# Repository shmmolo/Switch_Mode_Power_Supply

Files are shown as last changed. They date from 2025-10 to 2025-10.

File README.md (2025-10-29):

# 25 W @ 9 V Flyback SMPS Charger with USB-PD

A compact isolated Flyback SMPS delivering 25 W power for USB-C PD fast charging, designed around TI’s UCC28750 controller.

## Features
- 220 VAC input → 9 V / 5 V output
- USB-PD communication via IP2721
- UCC28750 PWM controller + optocoupler feedback
- Schottky rectification and snubber protection
- 2-layer PCB with ground plane and isolation gap

## Components
- **U1:** UCC28750 Flyback Controller  
- **Q1:** NMOS primary switch  
- **U2:** PC817 Optocoupler  
- **U3:** TL431 Voltage Reference  
- **U4:** IP2721 USB-PD Controller  
- **D1–D5:** GBU4K + SS310 Schottky diodes  
- **T1:** Flyback Transformer (custom)  
- **C1–C12:** Filtering capacitors

## Output Specs
| Mode | Voltage | Current | Power |
|---|---|---|---|
| Default | 5 V | 2.8 A | 14 W |
| USB-PD | 9 V | 2.8 A | 25 W |

## Notes
PCB under layout stage – final design will feature 2-layer structure with dedicated GND plane, thermal reliefs, and isolation.

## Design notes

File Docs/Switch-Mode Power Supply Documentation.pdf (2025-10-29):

# 25 W @ 9 V SMPS Charger (USB-PD)

## Overview

This project is a Switch-Mode Power Supply (SMPS) in flyback configuration, delivering 25 W output power at 9 V DC.
It features USB Power Delivery (PD) communication for fast charging via a USB Type-C port and uses the UCC28750 flyback controller for high-efficiency operation with isolated feedback.
The design follows modern compact-charger topologies, combining power, feedback, and communication circuits on a single 2-layer PCB (GND plane on the bottom).

## Key Specifications

Parameter | Value
Input Voltage | 220 – 240 VAC
Output Voltage | 5 V / 9 V (USB-PD)
Output Current | up to 2.8 A
Output Power | 25 W max
Topology | Isolated Flyback
Switching Controller | TI UCC28750
Feedback Isolation | TL431 + PC817 Optocoupler
USB-PD Controller | IP2721
Efficiency (target) | ≈ 85 %
Transformer | Custom 2P:1S Flyback, optimized for 25 W

## Functional Description

### 1. AC Rectification & Filtering

- Input 220 VAC enters through a Phoenix terminal block.
- A GBU4K full-bridge rectifier converts AC to DC.
- Three 10 µF electrolytic capacitors connected in parallel smooth the rectified DC.
- High-value resistor divider (R1–R3) provides startup and reference bias for the control stage.

### 2. Snubber & Protection Network

- The RC-D snubber (R4, R5, C4, D4) suppresses voltage spikes caused by transformer leakage inductance.
- D4 is an ultrafast Schottky diode, protecting the primary switch and improving efficiency.

### 3. Control Stage – UCC28750

- UCC28750 operates in primary-side regulation (PSR) with valley-switching PWM for low switching loss.
- It drives the Q1 NMOS transistor, switching current through the transformer’s primary winding.
- Current-sense resistor (R7) monitors switch current, while gate resistor (R6) limits EMI and overshoot.
- The controller dynamically adjusts frequency and duty cycle based on optocoupler feedback.

### 4. Feedback Regulation

- The secondary voltage is sensed through a TL431 precision reference (U3) and PC817 optocoupler (U2).
- When output voltage rises, TL431 conducts more, driving the optocoupler LED to adjust the duty cycle, maintaining stable regulation.
- This ensures precise and isolated voltage feedback between primary and secondary sides.

### 5. Output Rectification & Filtering

- The flyback transformer’s secondary output is rectified by D5 Schottky diode (low forward drop).
- Three 820 µF capacitors (C10–C12) filter the output to achieve low ripple and stable DC.

### 6. USB-PD Communication

- The IP2721 controller (U4) handles USB Power Delivery negotiation through CC1/CC2 lines.
- It communicates desired voltage/current profiles to the connected device (5 V / 9 V).
- Q2 NMOS acts as a high-side switch for VBUS control during protocol handshakes.
- Final output is provided via a USB Type-C receptacle, with shielding and ESD protection.

## PCB Design Overview

- 2-Layer PCB with bottom GND plane and isolated high-voltage creepage clearances.
- Primary and secondary grounds separated with safety isolation gap.
- Short and wide switch-node trace for reduced ringing and EMI.
- Transformer footprint (T1) centered for balanced heat distribution.
- Compact layout suitable for integration in a USB-C wall charger enclosure.

## Applications

- USB-C fast chargers (5 V / 9 V profiles)
- Compact SMPS adapters up to 25 W
- Isolated DC power sources for embedded systems
- Educational design for USB-PD + Flyback topology integration

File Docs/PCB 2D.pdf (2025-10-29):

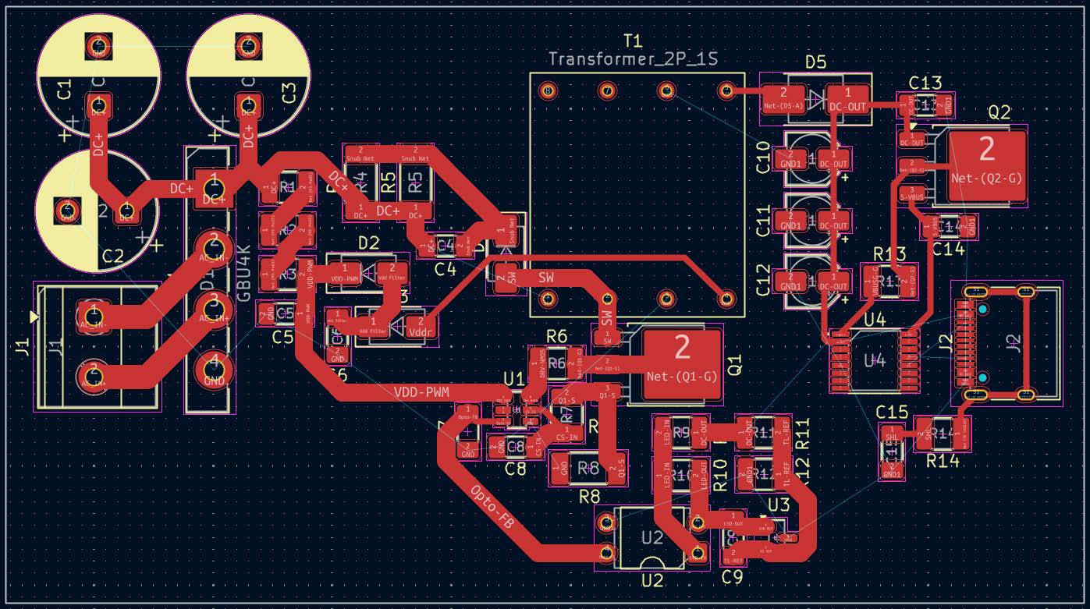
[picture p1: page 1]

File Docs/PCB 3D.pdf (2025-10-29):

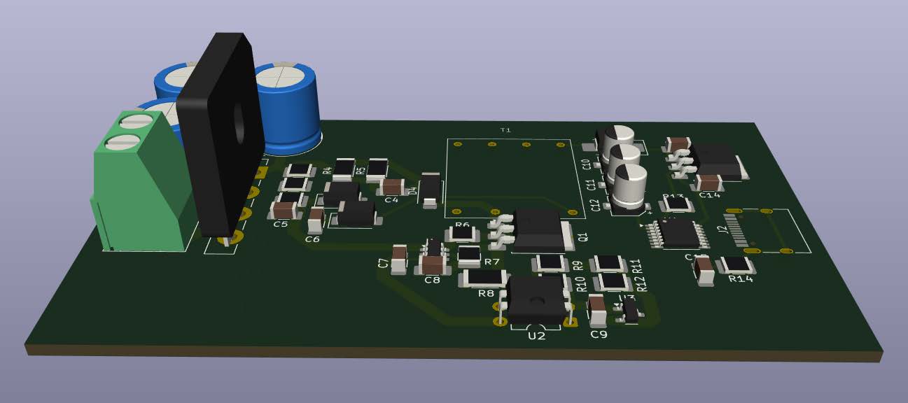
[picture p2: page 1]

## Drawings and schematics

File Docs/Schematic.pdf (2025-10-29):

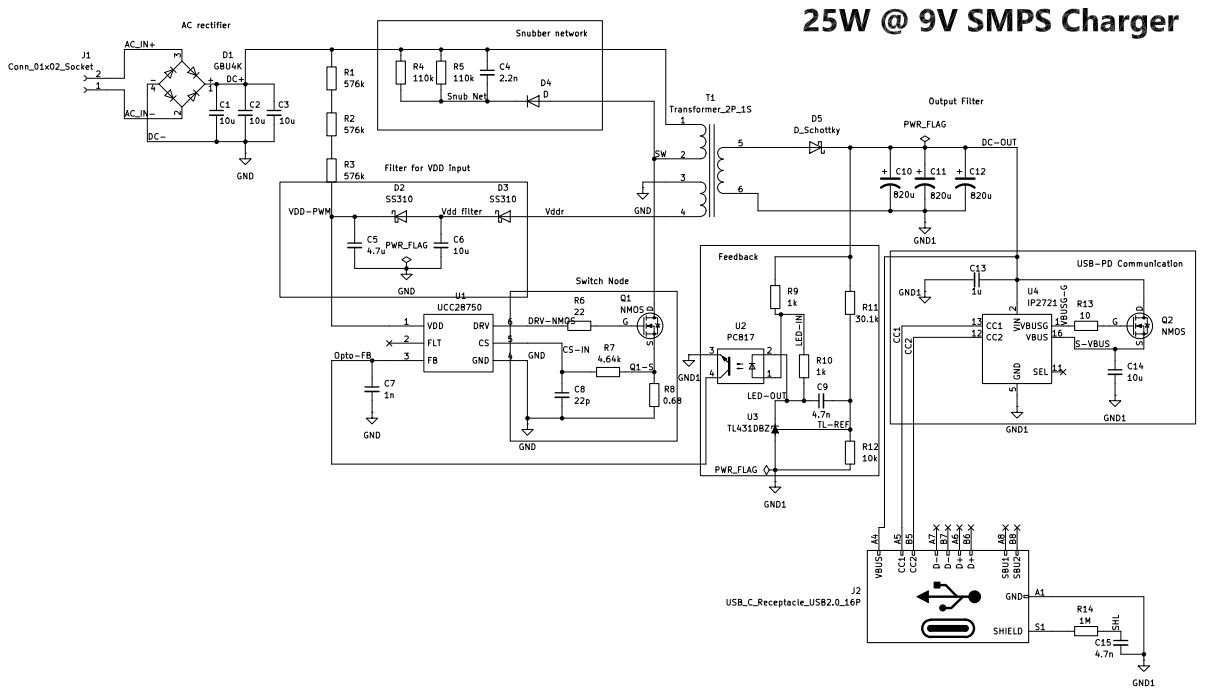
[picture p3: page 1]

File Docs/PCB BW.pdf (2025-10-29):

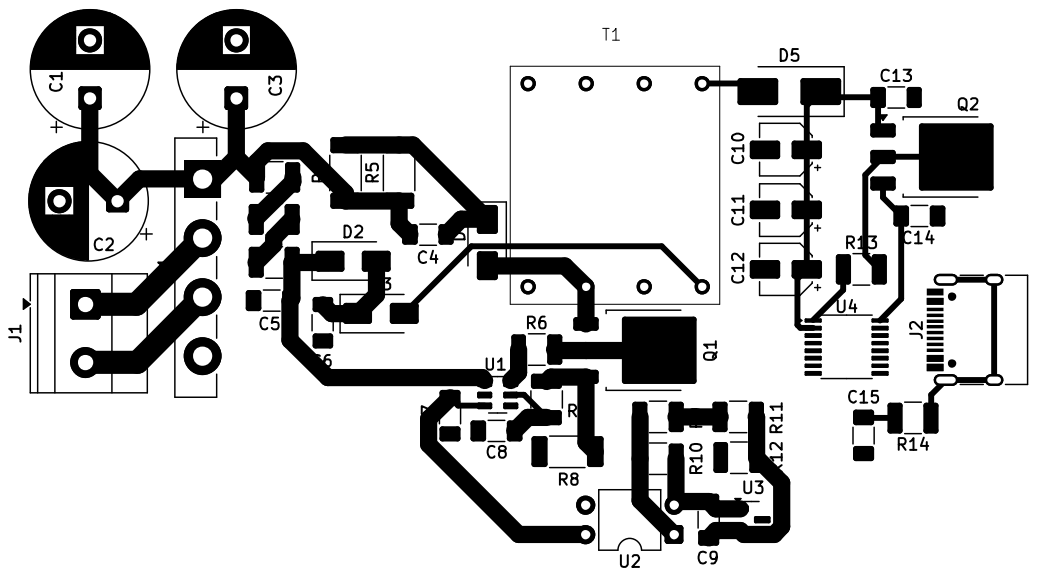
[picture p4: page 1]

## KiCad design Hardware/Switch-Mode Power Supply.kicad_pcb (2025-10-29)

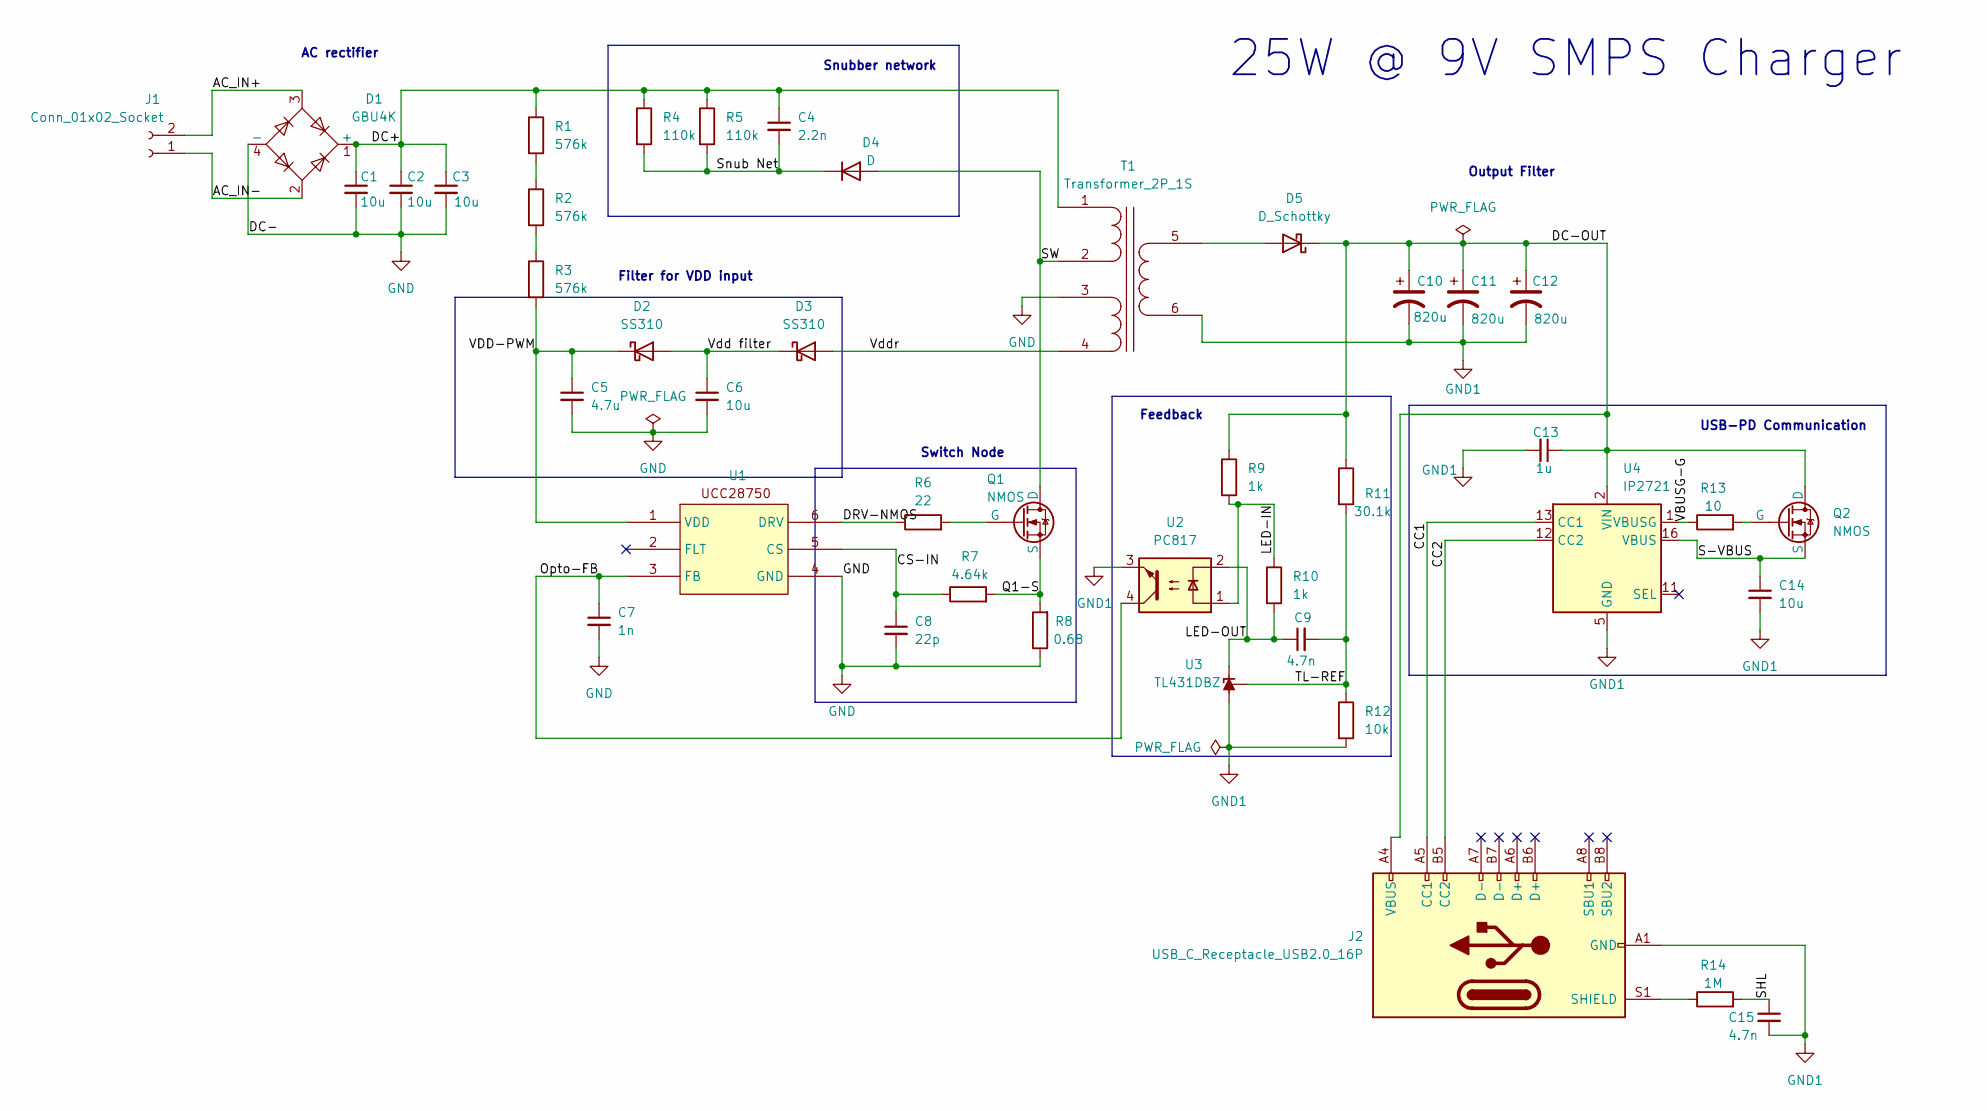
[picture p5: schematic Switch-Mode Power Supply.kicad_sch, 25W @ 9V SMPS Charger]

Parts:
C1, C2, C3: 10u; CP_Radial_D10.0mm_P5.00mm
C4: 2.2n; C_1206_3216Metric_Pad1.33x1.80mm_HandSolder
C5: 4.7u; C_1206_3216Metric_Pad1.33x1.80mm_HandSolder
C6, C14: 10u; C_1206_3216Metric_Pad1.33x1.80mm_HandSolder
C7: 1n; C_1206_3216Metric_Pad1.33x1.80mm_HandSolder
C8: 22p; C_1206_3216Metric_Pad1.33x1.80mm_HandSolder
C9, C15: 4.7n; C_1206_3216Metric_Pad1.33x1.80mm_HandSolder
C10, C11, C12: 820u; CP_Elec_4x5.4
C13: 1u; C_1206_3216Metric_Pad1.33x1.80mm_HandSolder
D1: GBU4K; Diode_Bridge_Vishay_GBU
D2, D3: SS310; D_SMA
D4: D; D_SMA
D5: D_Schottky; D_SMB_Handsoldering
J1: Conn_01x02_Socket; TerminalBlock_Phoenix_MKDS-1,5-2_1x02_P5.00mm_Horizontal
J2: USB_C_Receptacle_USB2.0_16P; USB_C_Receptacle_HRO_TYPE-C-31-M-12
Q1, Q2: NMOS; TO-252-3_TabPin2
R1, R2, R3: 576k; R_1210_3225Metric_Pad1.30x2.65mm_HandSolder
R4, R5: 110k; R_2010_5025Metric_Pad1.40x2.65mm_HandSolder
R6: 22; R_1210_3225Metric_Pad1.30x2.65mm_HandSolder
R7: 4.64k; R_1210_3225Metric_Pad1.30x2.65mm_HandSolder
R8: 0.68; R_2010_5025Metric_Pad1.40x2.65mm_HandSolder
R9, R10: 1k; R_1210_3225Metric_Pad1.30x2.65mm_HandSolder
R11: 30.1k; R_1210_3225Metric_Pad1.30x2.65mm_HandSolder
R12: 10k; R_1210_3225Metric_Pad1.30x2.65mm_HandSolder
R13: 10; R_1210_3225Metric_Pad1.30x2.65mm_HandSolder
R14: 1M; R_1210_3225Metric_Pad1.30x2.65mm_HandSolder
T1: Transformer_2P_1S; B66417G0000X149
U1: SOT-23-6
U2: PC817; DIP-4_W7.62mm
U3: TL431DBZ; SOT-23
U4: IP2721; TSSOP-16_4.4x5mm_P0.65mm

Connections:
/AC_IN+: D1.3, J1.2
/AC_IN-: D1.2, J1.1
/CC1: J2.A5 (CC1), U4.13 (CC1)
/CC2: J2.B5 (CC2), U4.12 (CC2)
/CS-IN: C8.1, R7.1, U1.5 (CS)
/DC+: C1.1, C2.1, C3.1, C4.1, D1.1 (+), R1.1, R4.1, R5.1, T1.1
/DC-OUT: C10.1, C11.1, C12.1, C13.1, D5.1 (K), J2.A4 (VBUS), J2.A9 (VBUS), J2.B4 (VBUS), J2.B9 (VBUS), Q2.1 (D), R9.1, R11.1, U4.2 (VIN)
/DRV-NMOS: R6.1, U1.6 (DRV)
/LED-IN: R9.2, R10.1, U2.1
/LED-OUT: C9.1, R10.2, U2.2, U3.1 (K)
/Opto-FB: C7.1, U1.3 (FB), U2.4
/Q1-S: Q1.3 (S), R7.2, R8.2
/S-VBUS: C14.1, Q2.3 (S), U4.16 (VBUS)
/SHL: C15.1, R14.2
/SW: D4.2 (A), Q1.1 (D), T1.2
/Snub Net: C4.2, D4.1 (K), R4.2, R5.2
/TL-REF: C9.2, R11.2, R12.1, U3.2 (REF)
/VBUSG-G: R13.1, U4.1 (VBUSG)
/VDD-PWM: C5.1, D2.1 (K), R3.2, U1.1 (VDD)
/Vdd filter: C6.1, D2.2 (A), D3.1 (K)
/Vddr: D3.2 (A), T1.4 (AUX2)
GND: C1.2, C2.2, C3.2, C5.2, C6.2, C7.2, C8.2, D1.4 (-), R8.1, T1.3 (AUX1), U1.4 (GND)
GND1: C10.2, C11.2, C12.2, C13.2, C14.2, C15.2, J2.A1 (GND), J2.A12 (GND), J2.B1 (GND), J2.B12 (GND), R12.2, T1.6 (S2), U2.3, U3.3 (A), U4.5 (GND)
unnamed: D5.2 (A), T1.5 (S1)
unnamed: J2.S1 (SHIELD), R14.1
unnamed: Q1.2 (G), R6.2
unnamed: Q2.2 (G), R13.2
unnamed: R1.2, R2.1
unnamed: R2.2, R3.1

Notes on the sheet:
AC rectifier
Output Filter
Feedback
Snubber network
Switch Node
USB-PD Communication
25W @ 9V SMPS Charger
Filter for VDD input

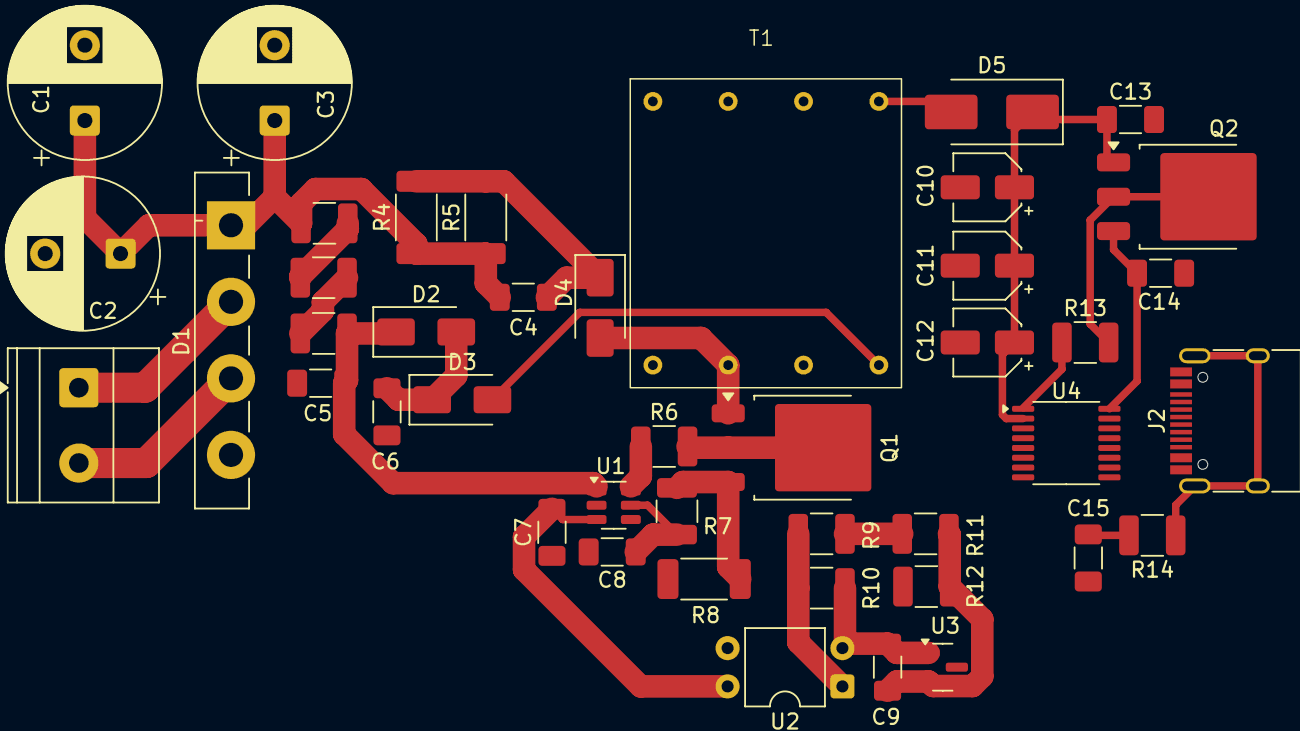
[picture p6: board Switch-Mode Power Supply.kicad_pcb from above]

Board: 2 copper layers, 43 parts (0 on the bottom side), 29 nets.

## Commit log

2025-10-29 Update and rename Switch-Mode Power Supply.kicad_pcb to Hardware/Switch-Mode Power Supply.kicad_pcb
    [Switch-Mode Power Supply.kicad_pcb]
2025-10-29 Update and rename Switch-Mode Power Supply.kicad_sch to Hardware/Switch-Mode Power Supply.kicad_sch
    [Switch-Mode Power Supply.kicad_sch]
2025-10-29 Added to Hardware
    [Switch-Mode Power Supply.kicad_pcb]
